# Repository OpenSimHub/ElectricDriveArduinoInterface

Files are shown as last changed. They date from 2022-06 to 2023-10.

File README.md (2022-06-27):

# ElectricDriveArduinoInterface

This repositoy contains the source files for the Electric Drive Ardunio Interface that was developed during the Master's Thesis of [@AnnikenKva](https://github.com/AnnikenKva) at the [University of South-Eastern Norway](https://www.usn.no) in Spring 2022.

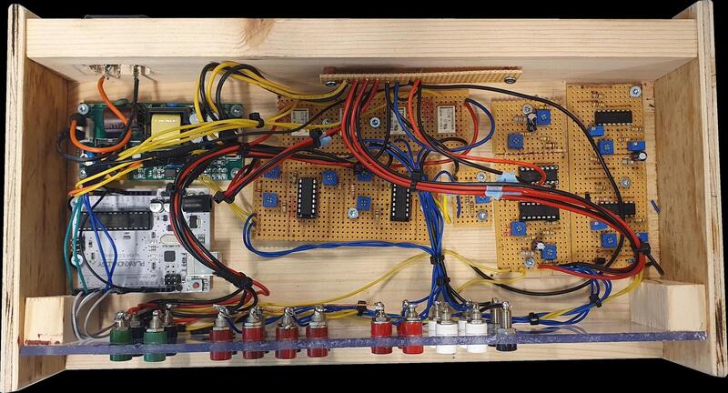
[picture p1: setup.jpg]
Image of physical setup


## Repository description

The repository is organised in the following way:

 * [`arduino/`](arduino): Sourcefile of Arduino programme
 * [`autocad/`](autocad): AutoCAD design file for the different board layouts
 * [`pdf/`](pdf): PDF files of the different board layouts
 * [`python/`](python): Source file for the Python scripts

In addtions the list of components can be found in
 * [`CompList.ods`](CompList.ods)

## License

Copyright &copy; 2022
*  [@AnnikenKva](https://github.com/AnnikenKva) and [@dietmarw](https://github.com/dietmarw)

All files in this repository are subject to the terms of the [Creative Commons Attribution-ShareAlike 4.0 International Public License](LICENSE).

## Contact

In case of questions or suggestions, feel free to open an issue or contact [@AnnikenKva](https://github.com/AnnikenKva) and [@dietmarw](https://github.com/dietmarw) directly.

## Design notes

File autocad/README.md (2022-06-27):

# File Description

 * [`05t010vero.dwg`](05t010vero.dwg): Stripboard layout for 0 − 5 V to 0 − 10 V converter circuit (editable file).
 * [`05tpm10vero.dwg`](05tpm10vero.dwg): Stripboard layout for 0 − 5 V to +- 10 V converter circuit (editable file).
 * [`420t05vero.dwg`](420t05vero.dwg): Stripboard layout for 4 - 20 mA to 0 − 5 V converter circuit (editable file).
 * [`pm10t05vero.dwg`](pm10t05vero.dwg): Stripboard layout for +- 10 V to 0 − 5 V converter circuit (editable file).
 * [`relaysvero.dwg`](relaysvero.dwg): Stripboard layout for 4-channel relay board (editable file).
 * [`fullWir.dwg`](fullWir.dwg): Full internal wiring diagram (editable file).
 * [`cBoxLayout.dwg`](cBoxLayout.dwg): Converter box xomponent layout / placement (editable file).

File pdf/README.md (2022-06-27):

# File Description

 * [`05t010vero.pdf`](05t010vero.pdf): Stripboard layout for 0 − 5 V to 0 − 10 V converter circuit (pdf file).
 * [`05tpm10vero.pdf`](05tpm10vero.pdf): Stripboard layout for 0 − 5 V to +- 10 V converter circuit (pdf file).
 * [`420t05vero.pdf`](420t05vero.pdf): Stripboard layout for 4 - 20 mA to 0 − 5 V converter circuit (pdf file).
 * [`pm10t05vero.pdf`](pm10t05vero.pdf): Stripboard layout for +- 10 V to 0 − 5 V converter circuit (pdf file).
 * [`relaysvero.pdf`](relaysvero.pdf): Stripboard layout for 4-channel relay board (pdf file).
 * [`fullWir.pdf`](fullWir.pdf): Full internal wiring diagram (pdf file).
 * [`cBoxLayout.pdf`](cBoxLayout.pdf): Converter box xomponent layout / placement (pdf file).

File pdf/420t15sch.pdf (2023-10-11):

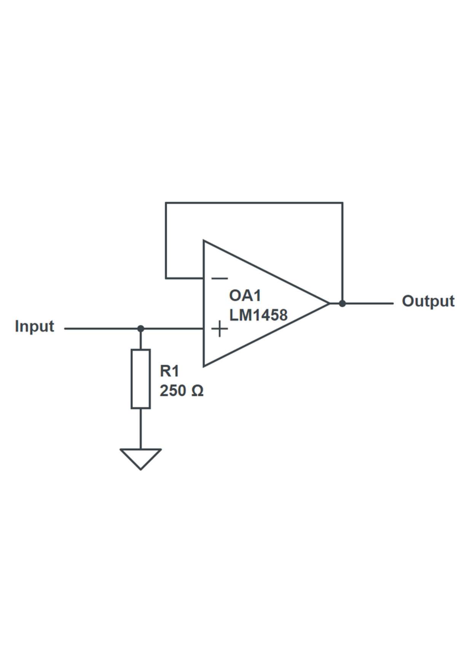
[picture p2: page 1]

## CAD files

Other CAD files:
autocad/fullWir.dwg
autocad/420t15vero.dwg
autocad/pm10t05vero.dwg
autocad/cBoxLayout.dwg
autocad/05t010vero.dwg
autocad/relaysvero.dwg
autocad/05tpm10vero.dwg

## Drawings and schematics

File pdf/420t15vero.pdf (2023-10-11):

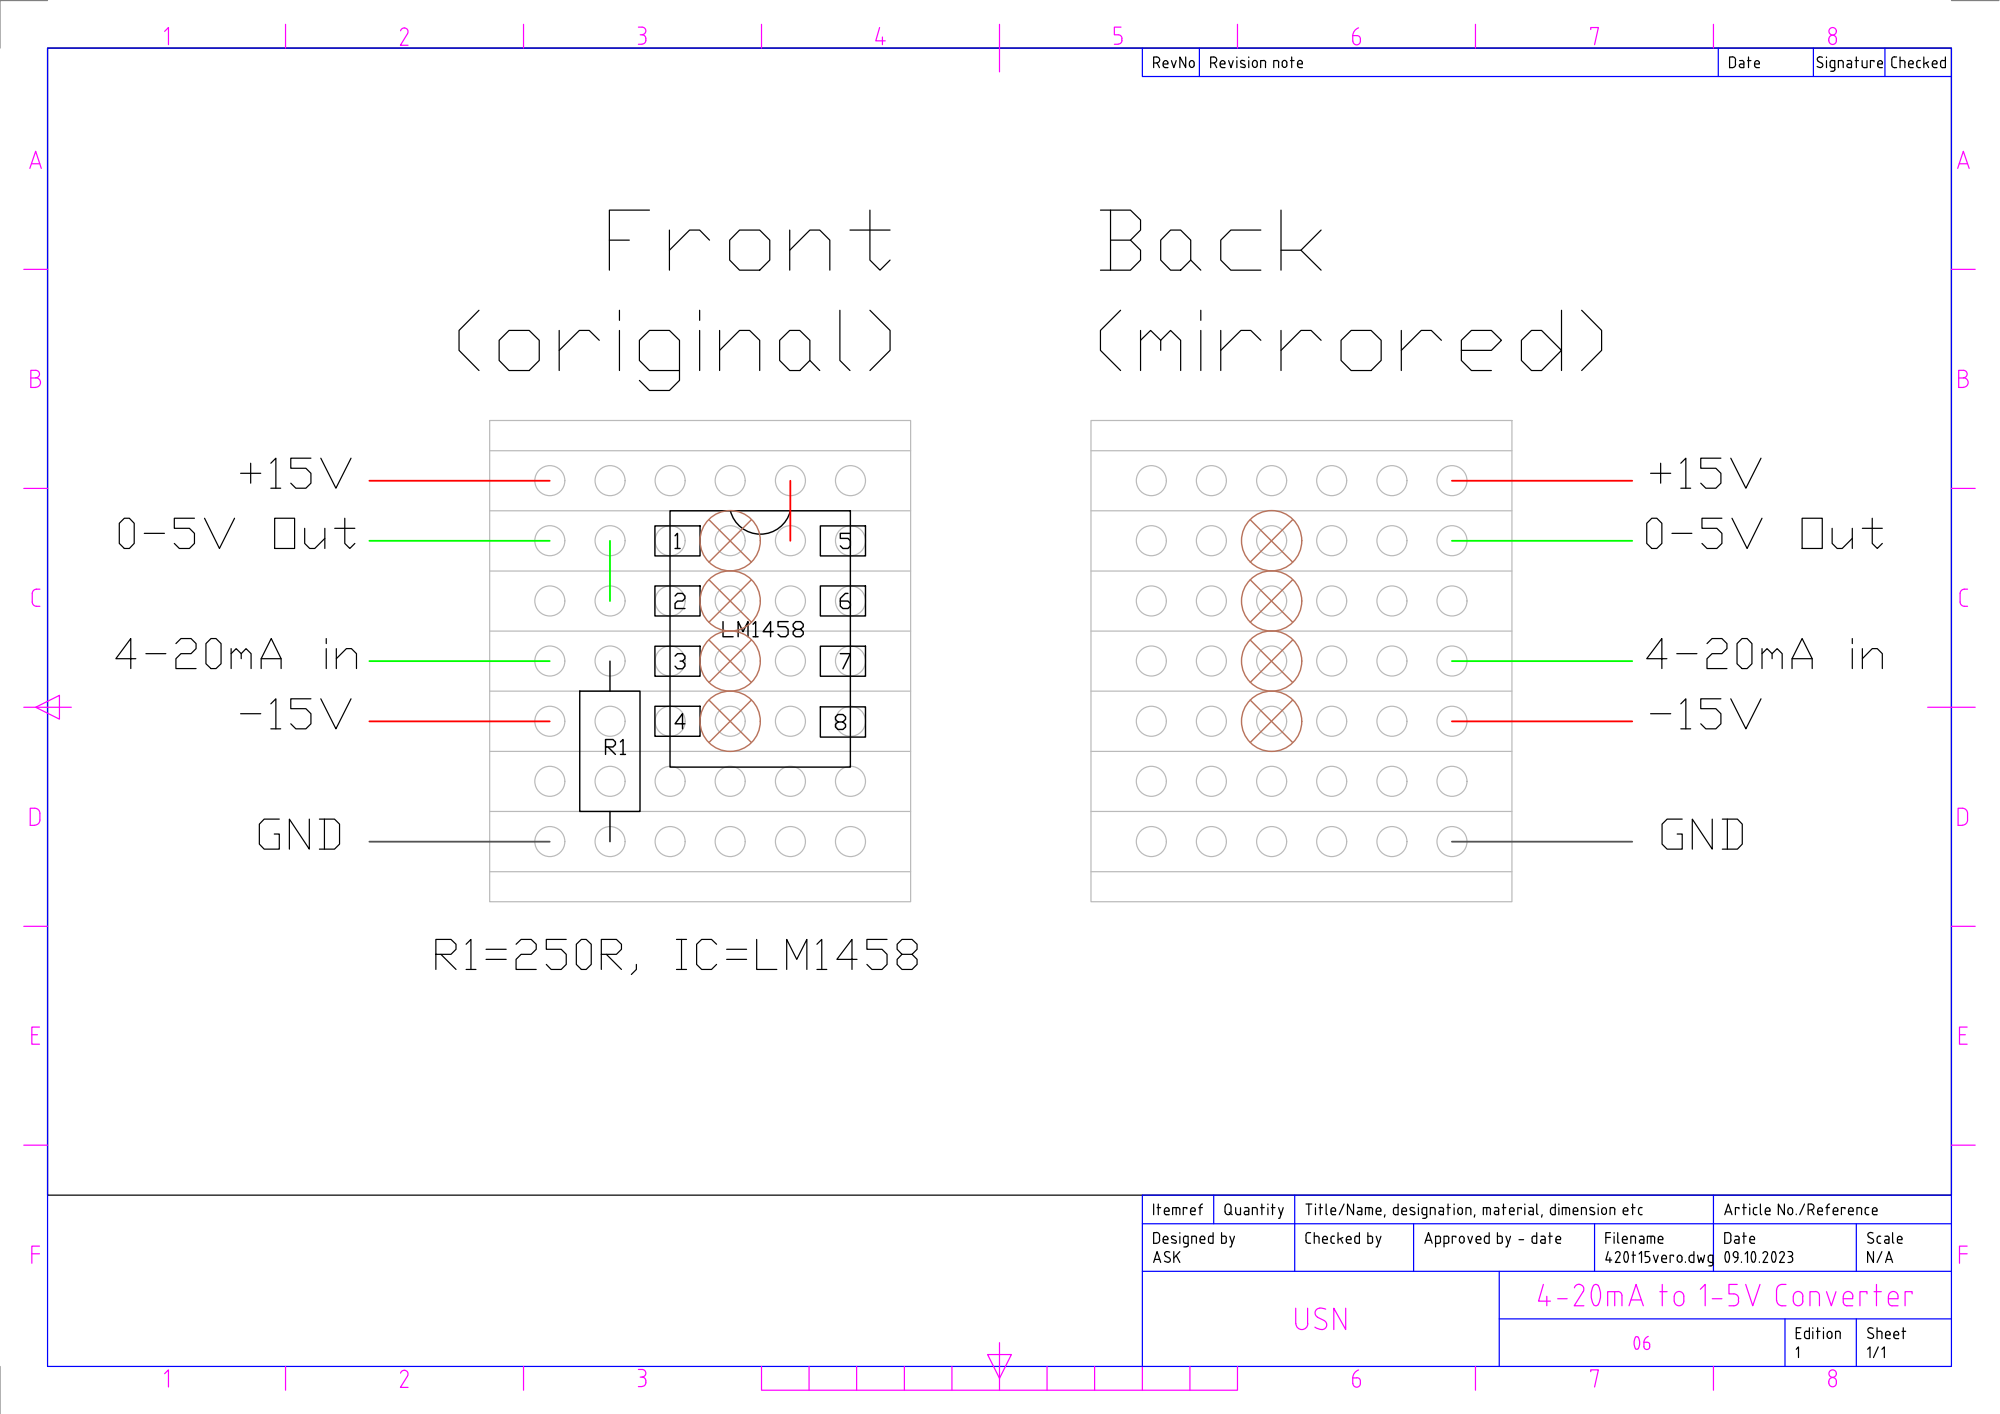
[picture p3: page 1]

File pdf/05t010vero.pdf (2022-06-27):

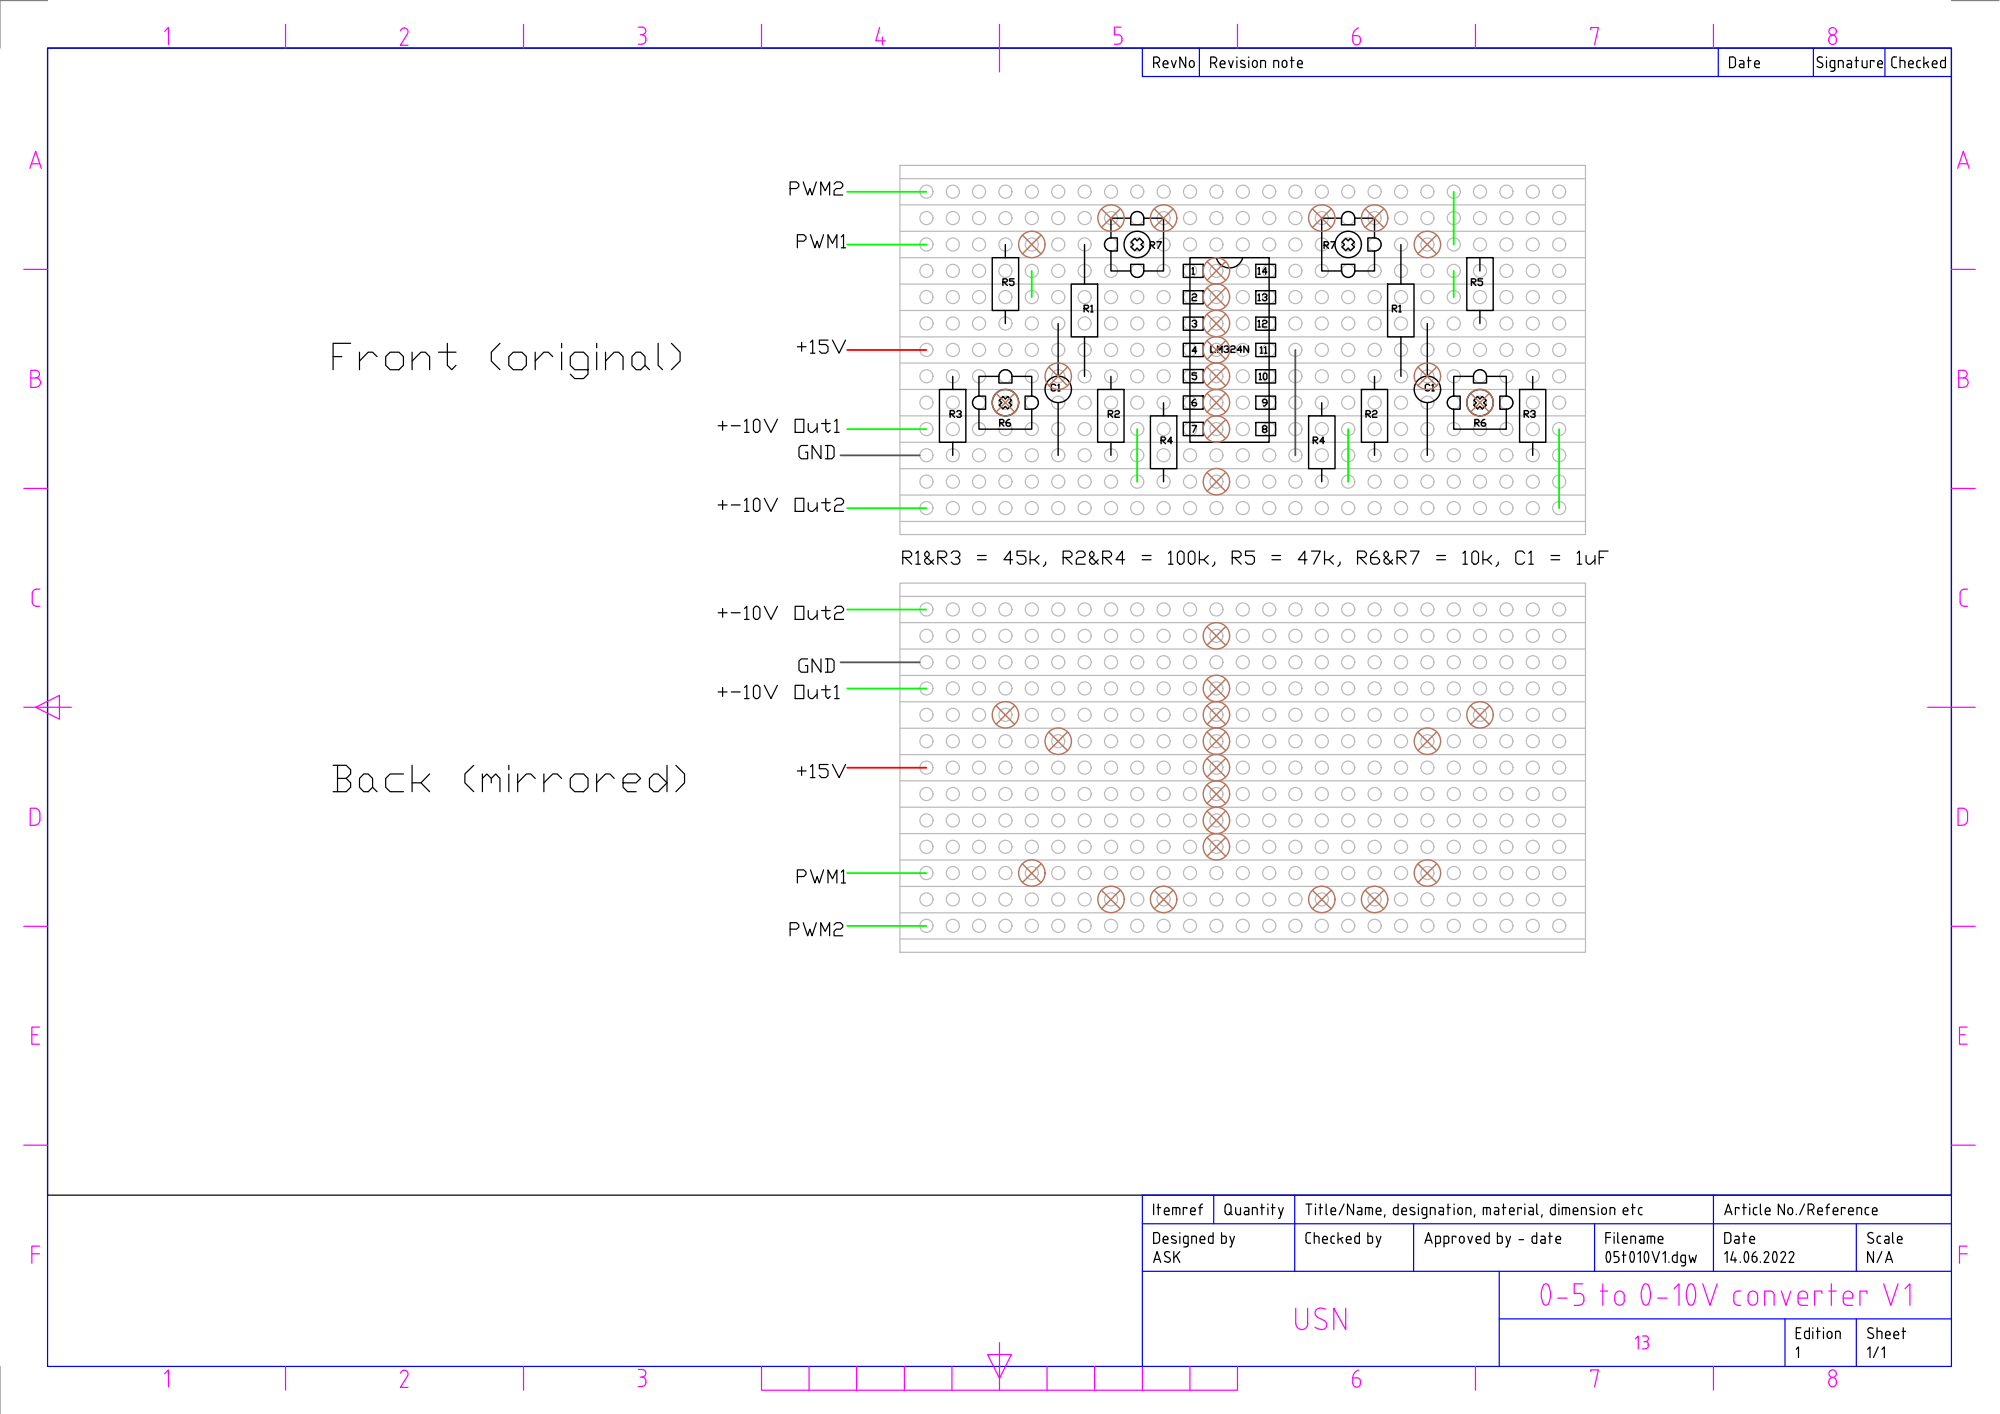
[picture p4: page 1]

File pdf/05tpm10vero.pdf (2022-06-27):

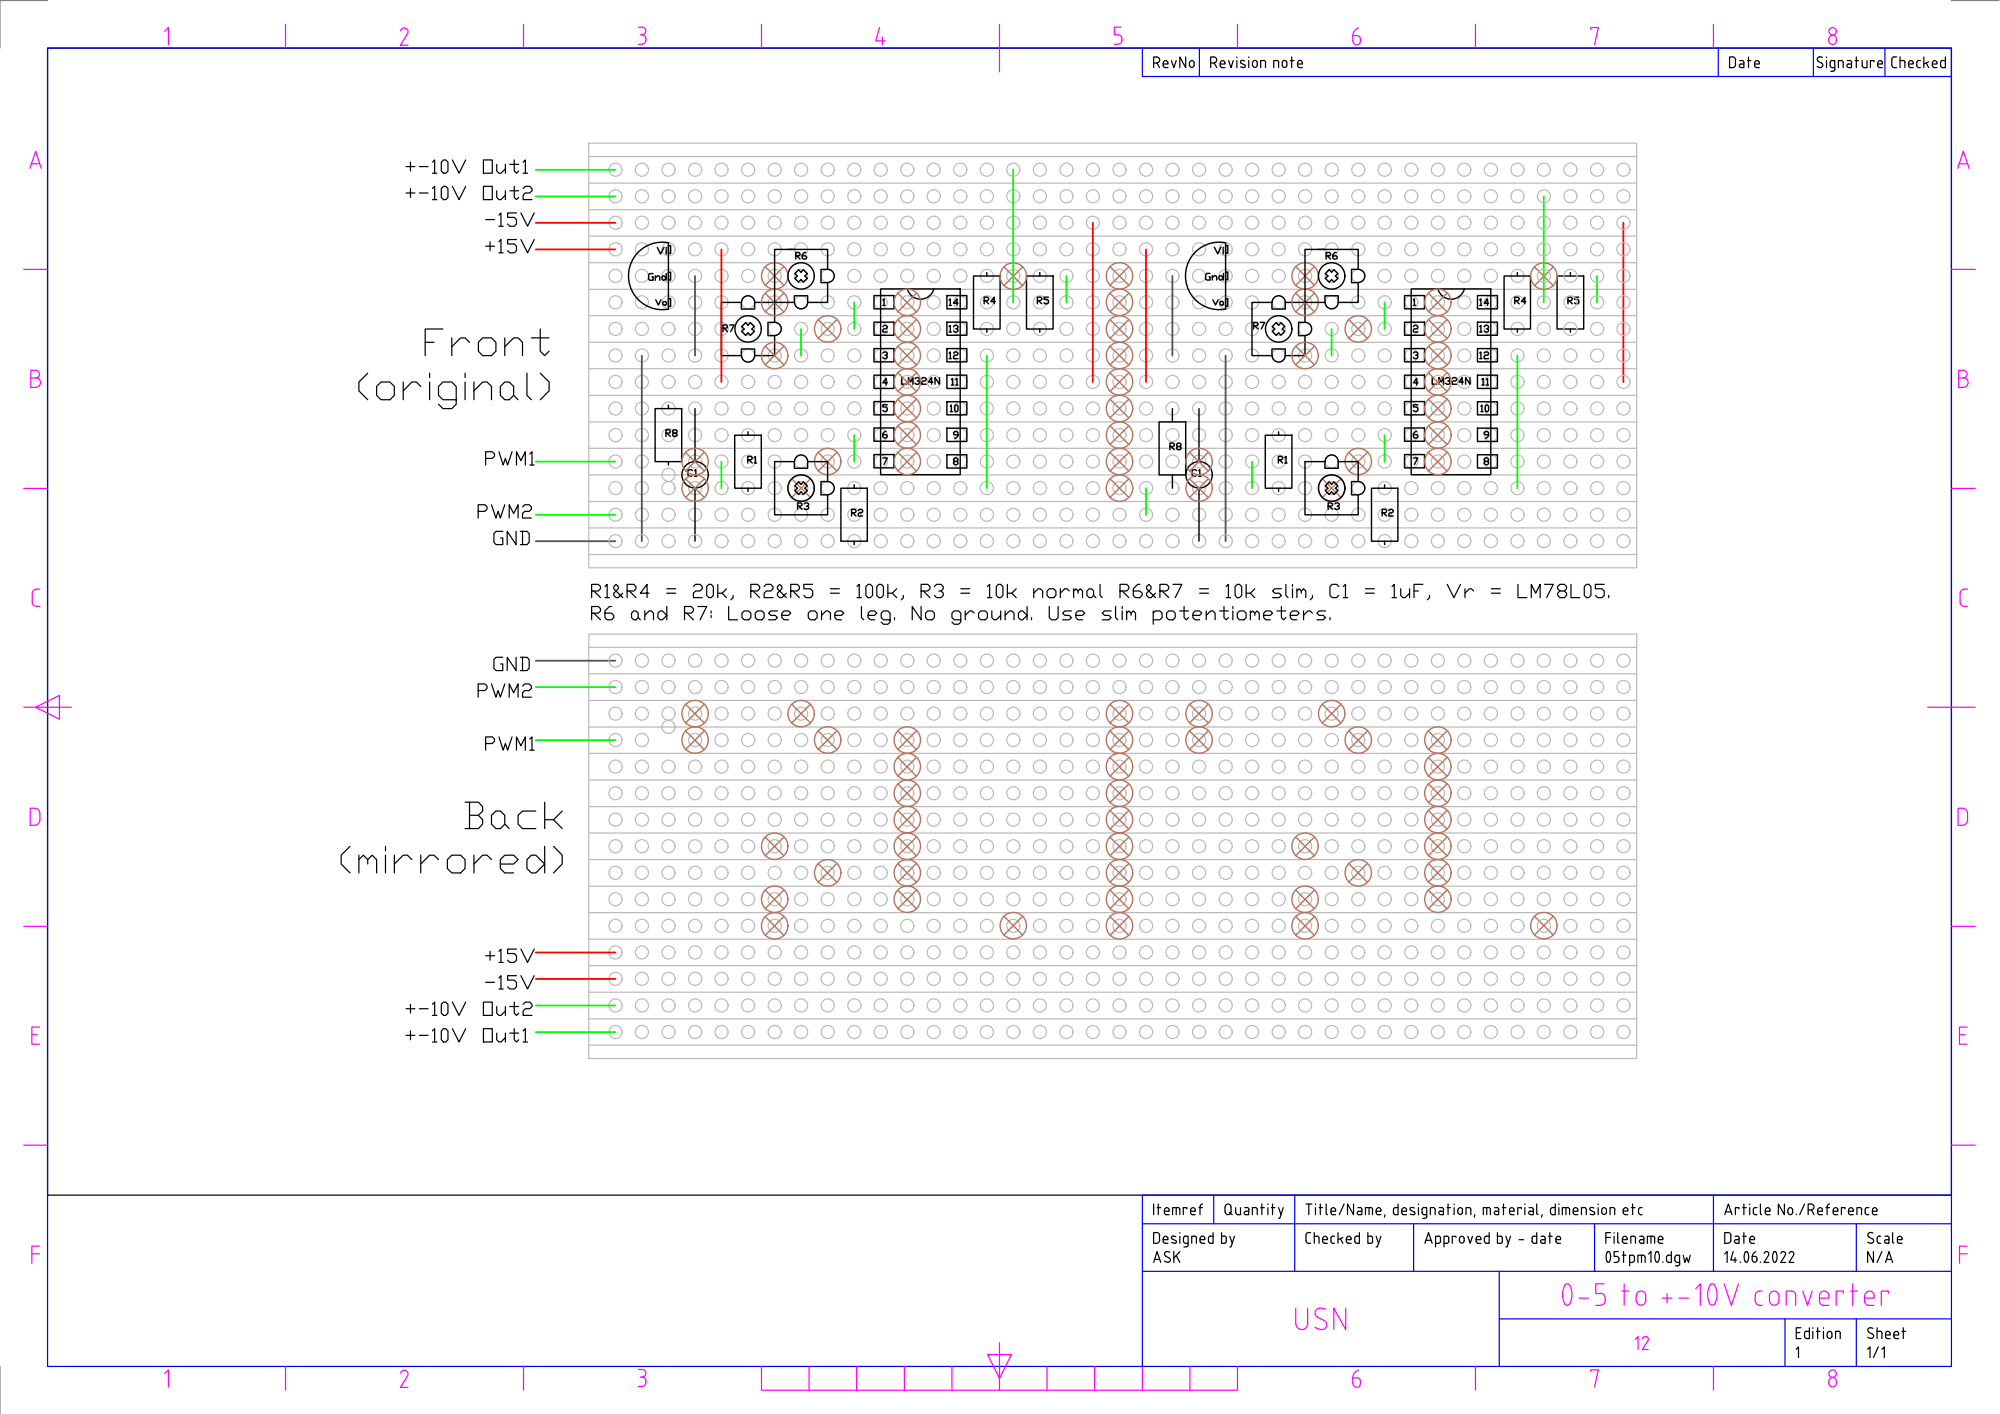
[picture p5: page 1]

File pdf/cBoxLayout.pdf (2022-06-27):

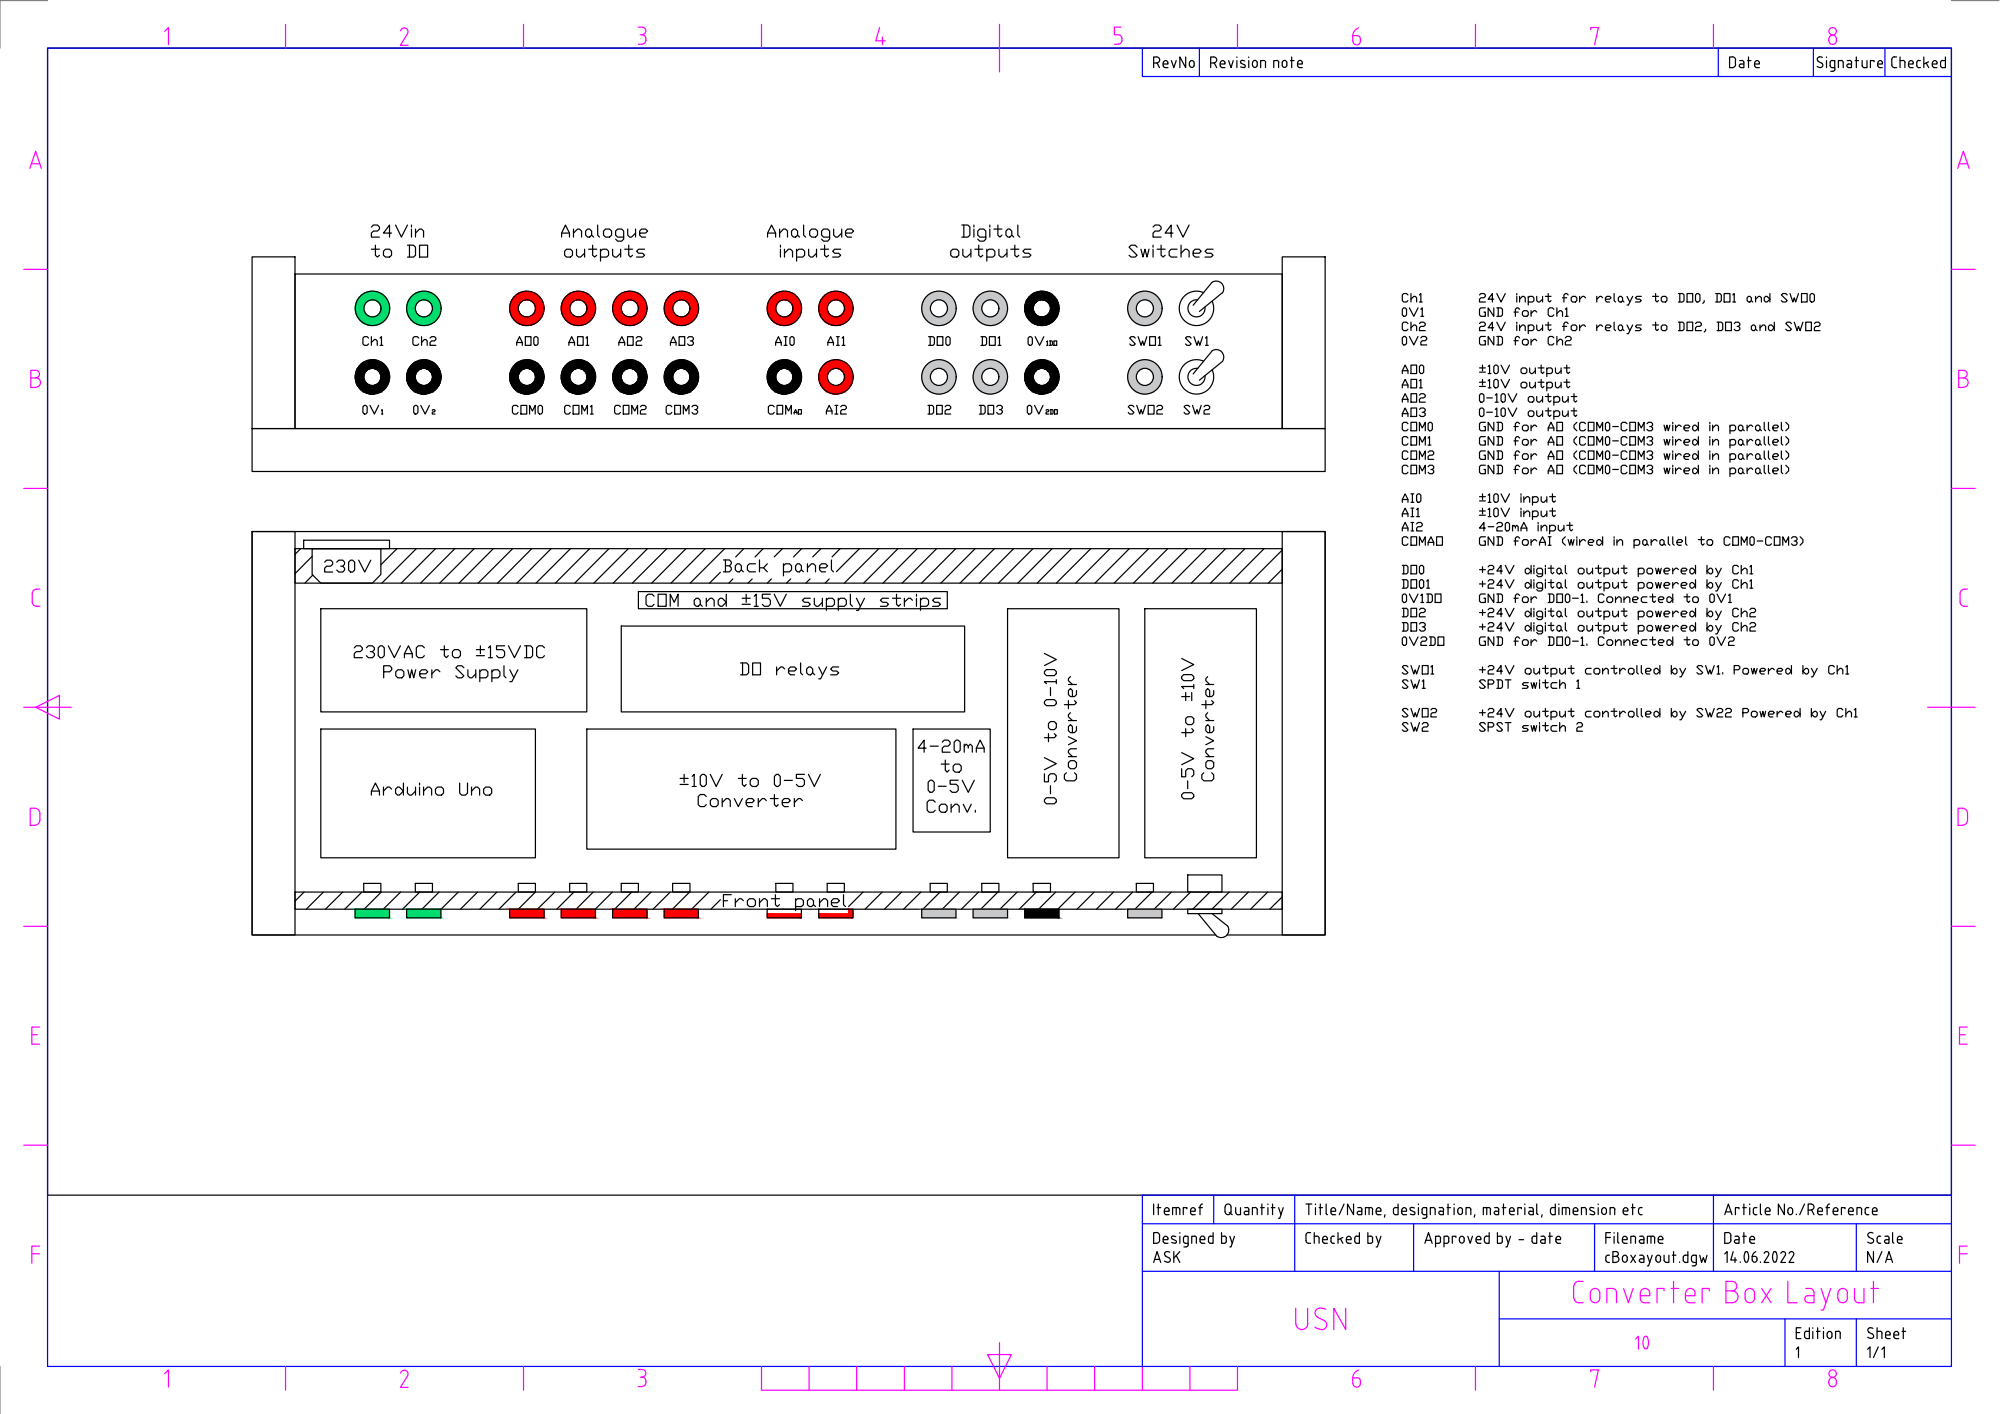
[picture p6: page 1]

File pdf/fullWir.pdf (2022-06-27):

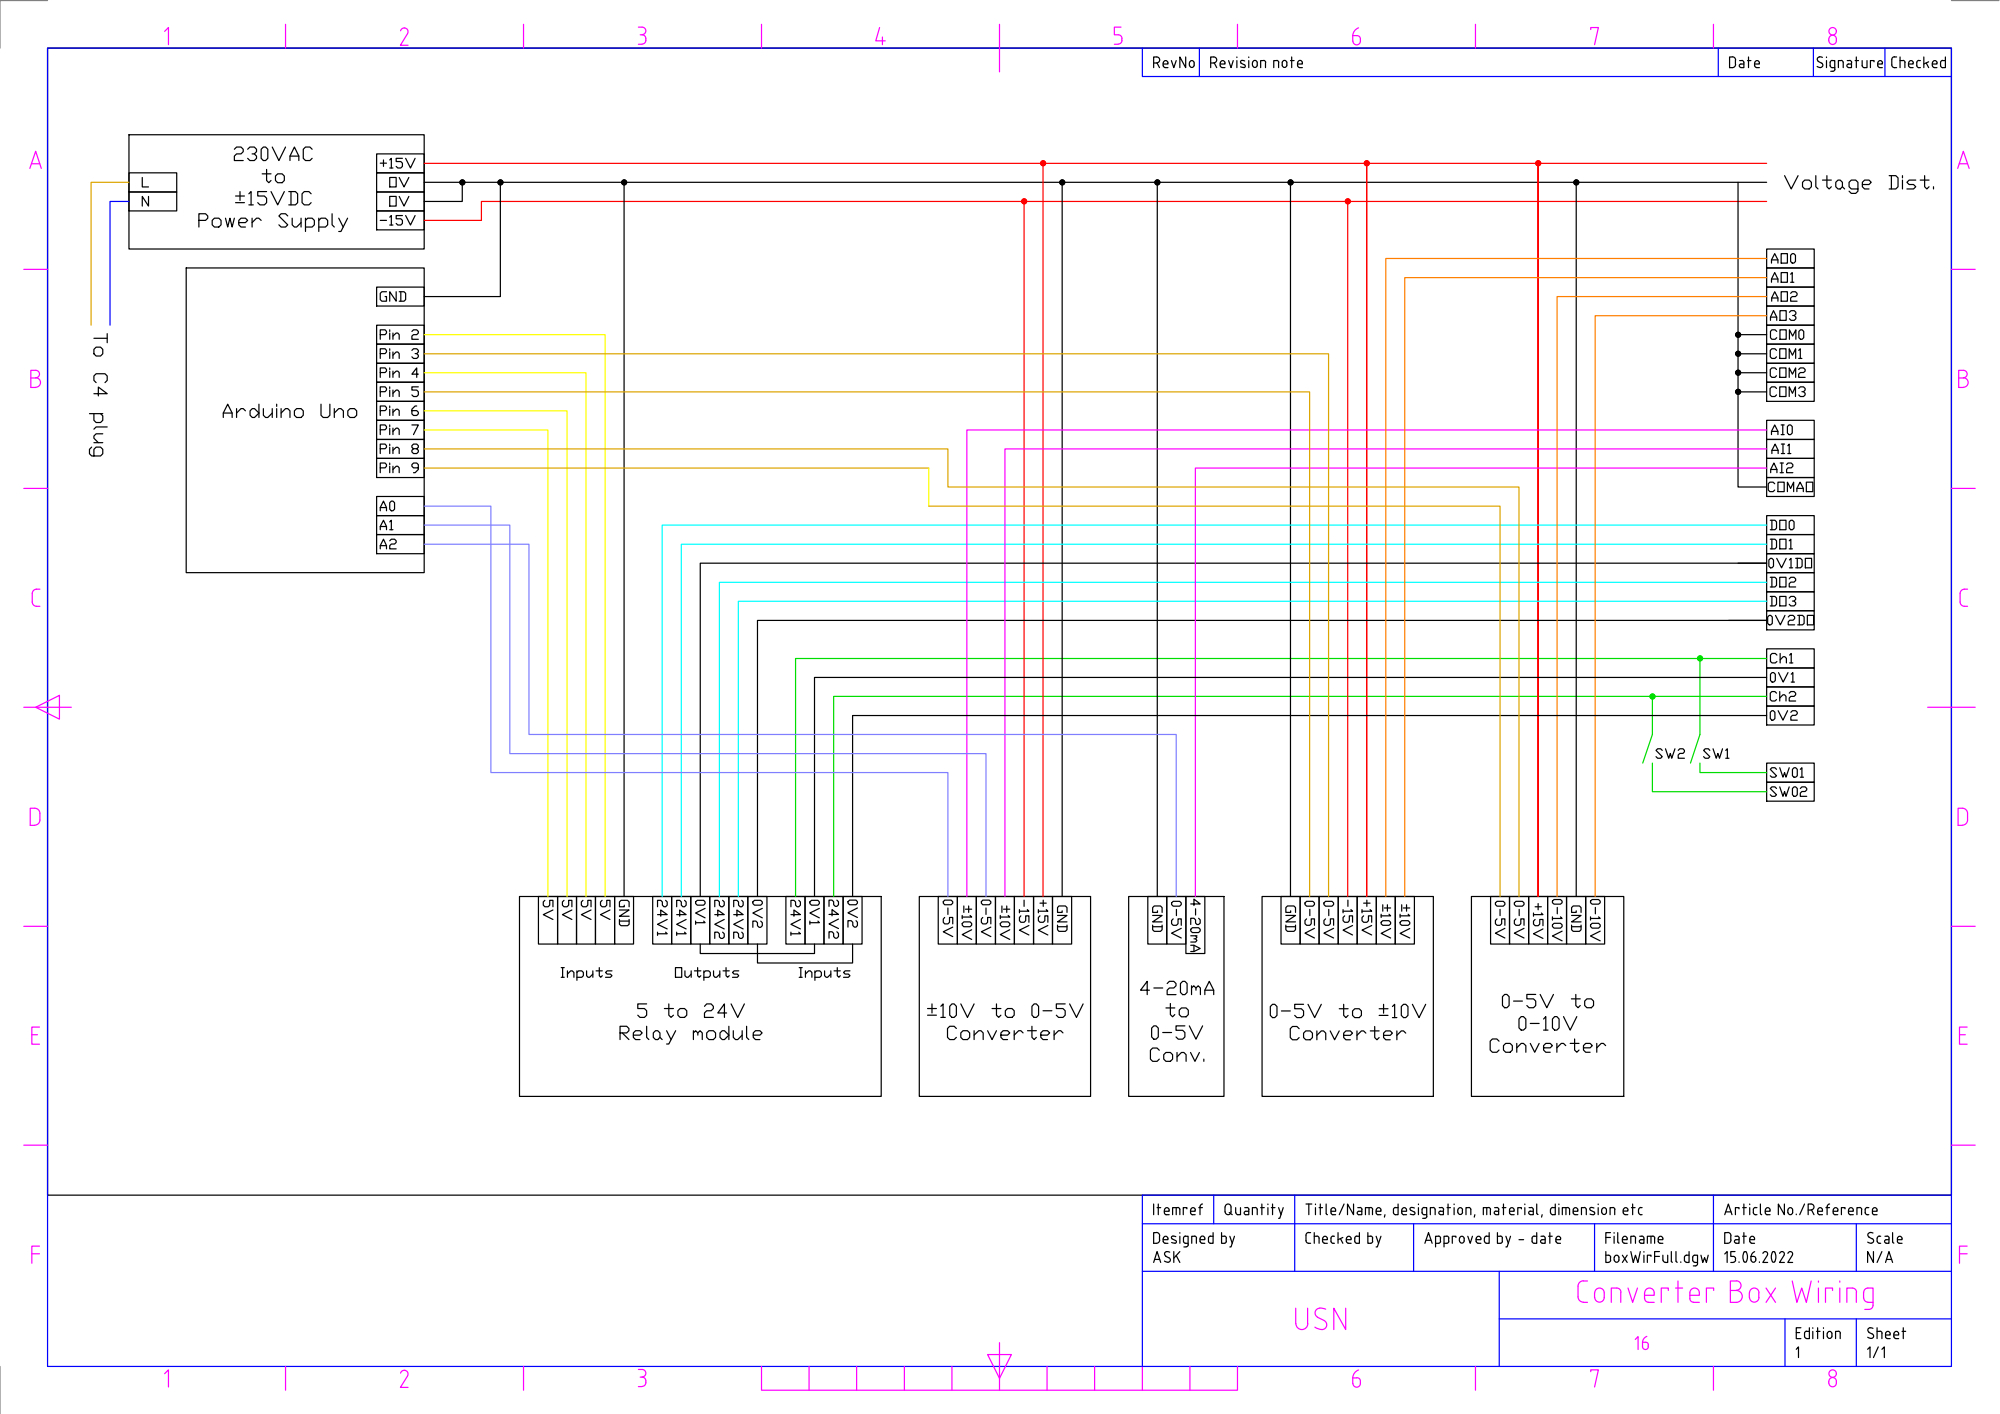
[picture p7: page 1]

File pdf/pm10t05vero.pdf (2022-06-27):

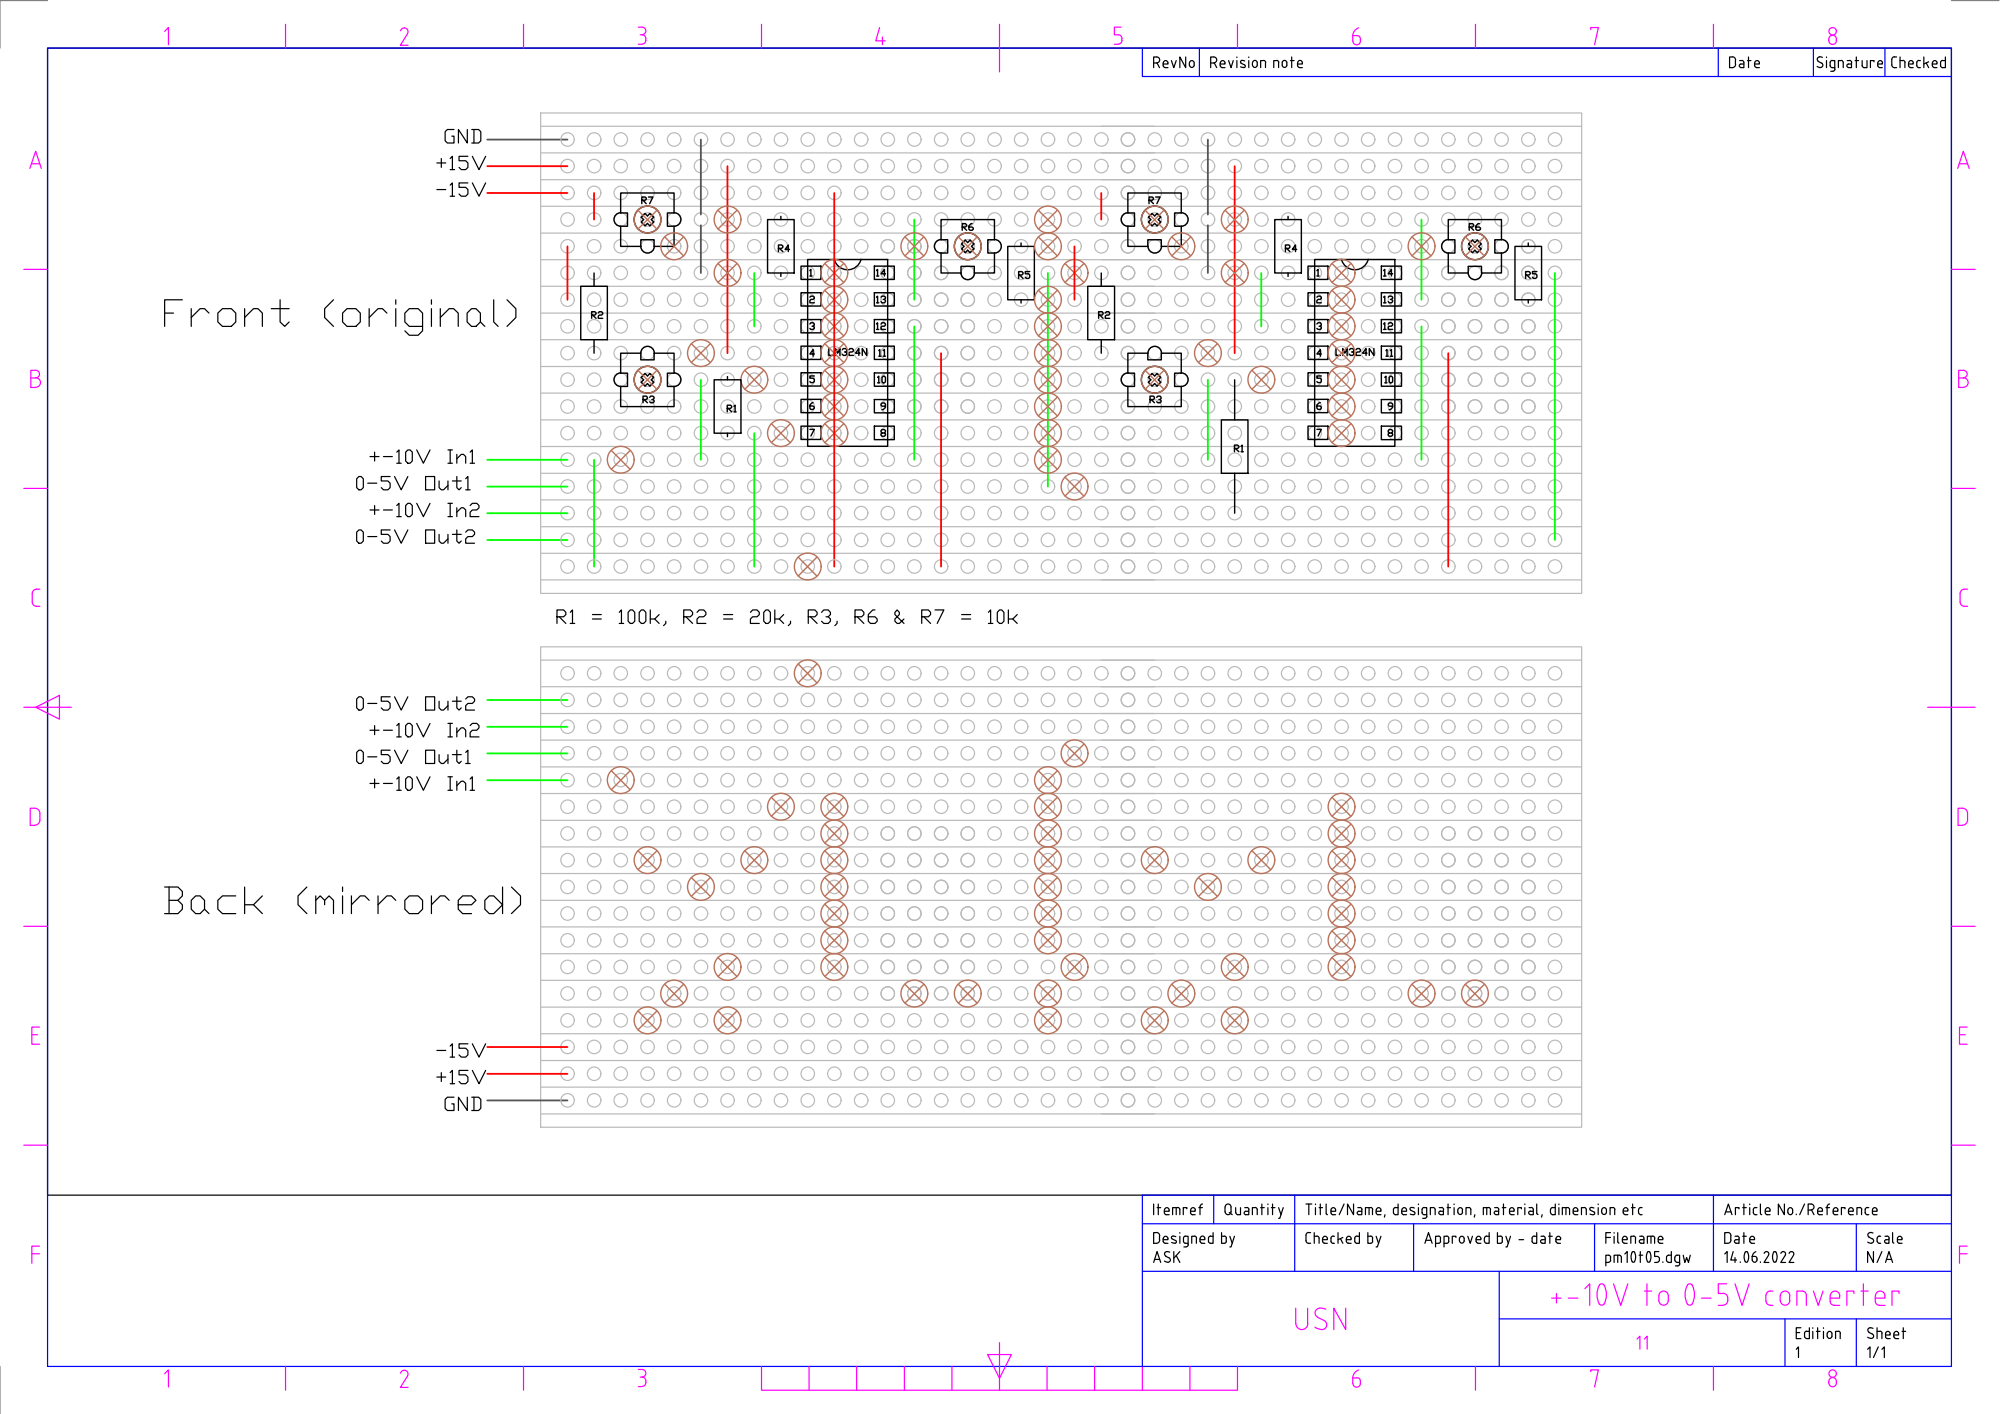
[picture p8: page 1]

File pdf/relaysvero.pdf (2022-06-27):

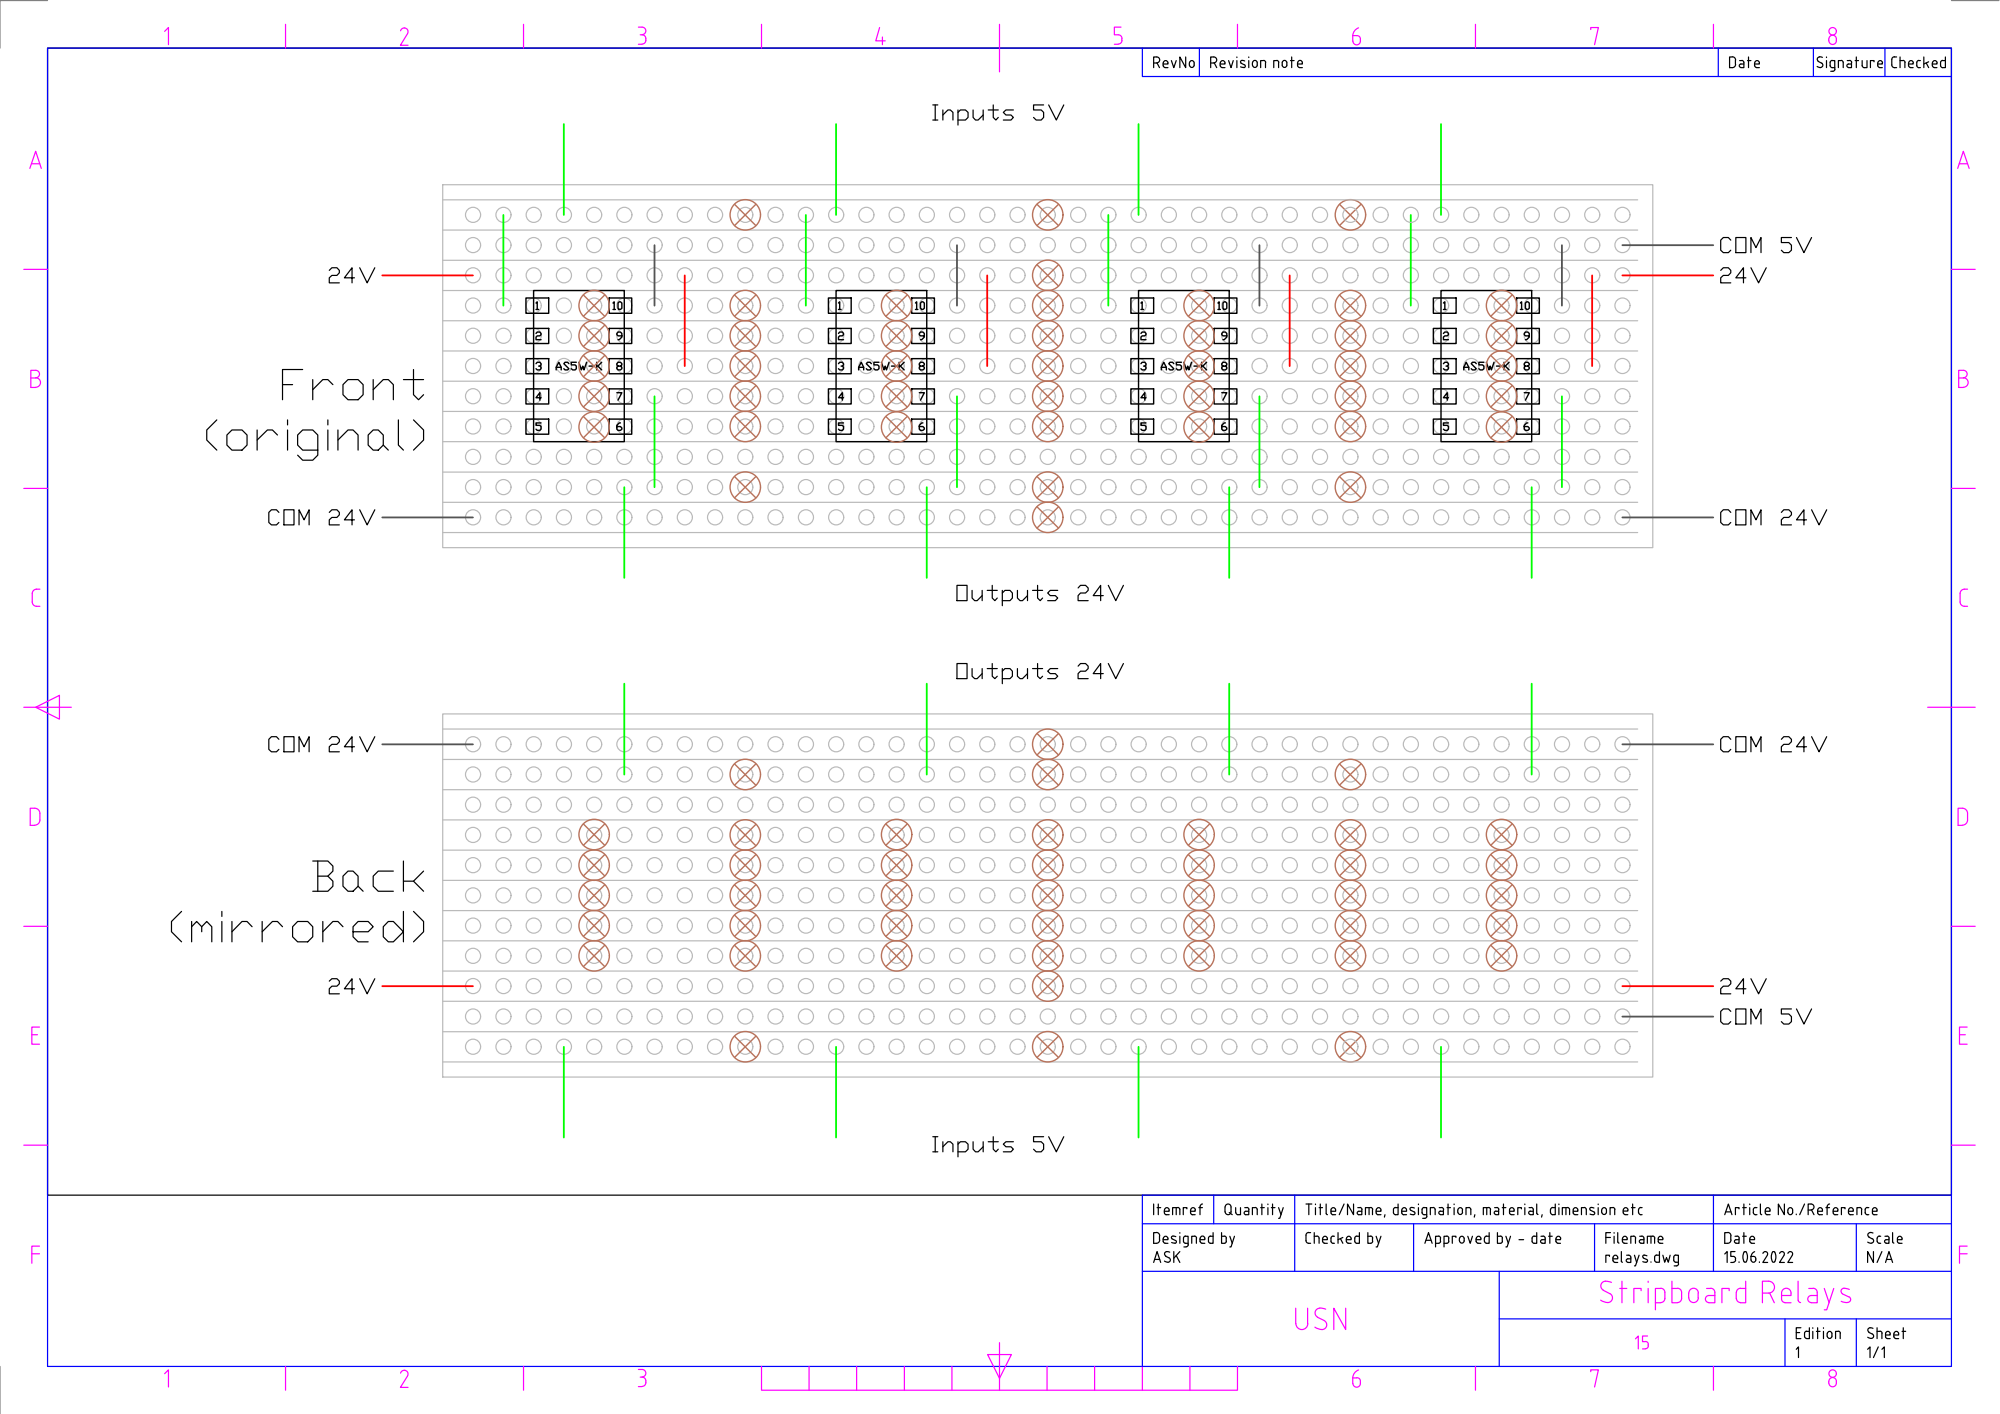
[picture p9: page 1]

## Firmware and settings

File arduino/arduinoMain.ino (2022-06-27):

/* Sketch for ARDUINO communication with Python.
 *  
 *  Part of master's thesis spring 2022.
 *  Anniken Semb Kvalsund
 *  Electrical Power Engineering.
 *  
 */

// Constants
const int AI[3] = {A0, A1, A2}; // Creates an array of all the analog inputs
byte noAI = (sizeof(AI)/sizeof(AI[0]));   // Finds the number of elements in AI array. To use in for loops etc

// Variables
int data1 = 0;          // Input information. Initialise to zero.
int i = 0;

bool readAI = false;
bool writeADO = false;
bool calibrateAO = false;
bool LEDcontr = false;

int AIs[10];            // For "storing" collected analogue input values
char AIstring[16];      // For storing AI values converted to string

// Write data constants and variables
const byte numChars = 16;
char receivedChars[numChars];   // an array to store the received data
byte ndx = 0;
boolean newData = false;
char analogDigital;
int channel;   // Converts the number recieved in channel number to an int
int chValConv; // Sends the char chVal to string toInt function, returned scaled and converted to int.
int outVal; // Output value to analogue PWM outputs.
bool LEDon = false; // LED controlling variable.

// Maxvalue to PWM outputs. Adjustable to ensure 5V, not more, is output at max.
int max_out_AO0 = 255; 
int max_out_AO1 = 255;
int max_out_AO2 = 255;
int max_out_AO3 = 255;

// Declare outputs
const int DO0 = 2;
const int DO1 = 4;
const int DO2 = 7;
const int DO3 = 8;

const int AO0 = 3;      // 0-10V
const int AO1 = 5;      // 0-10V
const int AO2 = 6;      // +-10V
const int AO3 = 9;      // +-10V


void setup() {
  // Setting up an initialise the serial communication
  Serial.begin(9600);       
  pinMode(LED_BUILTIN, OUTPUT);
  pinMode(DO0, OUTPUT);
  pinMode(DO1, OUTPUT);
  pinMode(DO2, OUTPUT);
  pinMode(DO3, OUTPUT);
  pinMode(AO0, OUTPUT);
  pinMode(AO1, OUTPUT);
  pinMode(AO2, OUTPUT);
  pinMode(AO3, OUTPUT);

}



void loop() {
if(Serial.available()>0){           // Return the number of bytes available on serial. if <0, = no info on serial.
  
  recvWithEndMarker();

  if(readAI == true){
    analoginputs();
    readAI = false;
  }

  if(writeADO == true){
    analogueOut();
    writeADO = false;
  }

  if(calibrateAO == true){
    calibrateAO_func();
    calibrateAO = false;
  }

  if (LEDcontr == true){
    LEDonoff();
    LEDcontr = false;
  }
  
  else{/* Do nothing*/}
  } // if serial available
} // Void loop 

//_____________________________________________________________________________________________
// Read analogue inputs

void analoginputs(){ 
  for ( i=0; i<=noAI; i++){
     AIs[i] = analogRead(AI[i]);
   } // for AI

   // Converting the analog input values to a single string with x's separating each value.
   sprintf(AIstring, "%dx%dx%d" , AIs[0],AIs[1],AIs[2]);                  
   Serial.println(AIstring);       // Writes data from AI to serial bus   
} // void analoginputs


//_____________________________________________________________________________________________
// Reads from Serial port until endChar '\n' is received.

void recvWithEndMarker() {
  char endMarker = '\n';
  char rc;
  boolean done = false;

  while (Serial.available() && !done) {
    rc = Serial.read();
    if (rc == endMarker) {
      done = true;
      newData  = true;
    }
    else {
      receivedChars[ndx++] = rc;
      if (ndx >= numChars)
        done = true;
    }
  }

  if (newData) {
    if (!parseInput()) { // if we call parseData it fails there is no need to process that data further.
      //Serial.println("String couldn't be parsed");
      newData = false;
    }
    ndx = 0;
  }
}


//_____________________________________________________________________________________________
// Splits the received string into its separate characters and stores them in globals

boolean parseInput() {
  int secondX = -1;
  String tempString;
  String chValConvtemp;
  char Buf[2];      // For converting string to char
  

  for (int i = 0; i < ndx; i++)
    //Serial.print(receivedChars[i]);
    //Serial.println();

  if (receivedChars[1] != 'x'){   // If no further values are read, ie not split by x'es
     if (receivedChars[0] == 'e'){ readAI = true;} // The readAI value is set to true, causing readAI function to run
     if (receivedChars[0] == 'h'){ LEDcontr = true; LEDon = true;}
     if (receivedChars[0] == 'i'){ LEDcontr = true; LEDon = false;}
    return false;}
  else {                          // If more than one value is transmitted

    if (receivedChars[0] == 'o' or receivedChars[0] == 'p'){ writeADO = true; analogDigital = receivedChars[0];} // Prepare to write values
    if (receivedChars[0] == 'q'){ calibrateAO = true;}   // Prepare to calibrate (using the same message system as writeADO
    
    for (int i = 3; i < ndx && secondX == -1; i++)
      if (receivedChars[i] == 'x')
        secondX = i;

    if (secondX == -1)
      return false;

    tempString = receivedChars;
    channel = tempString.substring(2, secondX).toInt();
    
    chValConvtemp = tempString.substring(secondX + 1, ndx);
    chValConvtemp.toCharArray(Buf, 2);
    chValConv = int(Buf[0]);

// Print for troubleshooting
    Serial.print("analogDigital -> ");
    Serial.println(analogDigital);
    Serial.print("channel -> ");
    Serial.println(channel);
    Serial.print("chValConv -> ");
    Serial.println(chValConv);
  }
  return true;
}

//_____________________________________________________________________________________________
// Write analogue and / or digital values

void analogueOut() { // Writes to analogue outputs

  if (newData == true) {
    // Result in an array with two elements. One A1/D2 etc and one Value/onoff

    if (analogDigital == 'o') {
      //Serial.println("Analogue");

      switch (channel) {
        case 0:
          //Serial.println("AO0");
          outVal = constrain((map(chValConv, 0, 100, 0, max_out_AO0)), 0, max_out_AO0);
          analogWrite(AO0, outVal);
          break;
        case 1:
          //Serial.println("AO1");
          outVal = constrain((map(chValConv, 0, 100, 0, max_out_AO1)), 0, max_out_AO1);
          analogWrite(AO1, outVal);
          break;
        case 2:
          //Serial.println("AO2");
          outVal = constrain((map(chValConv, 0, 100, 0, max_out_AO2)), 0, max_out_AO2);
          analogWrite(AO2, outVal);
          break;
        case 3:
          //Serial.println("AO3");
          outVal = constrain((map(chValConv, 0, 100, 0, max_out_AO3)), 0, max_out_AO3);
          analogWrite(AO3, outVal);
          break;
        default:
          //Serial.println("NaN");
          break;
      } // Switch case channel

    } // if recievedArray[0]=o

    else if (analogDigital == 'p') {
      //Serial.println("Digital");
      bool dContr = false;

      // Creating a "buffer"
      if (chValConv < 50){dContr = LOW;}
      else if (chValConv >= 50){dContr = HIGH;}
      else {dContr = LOW;}
      
      switch (channel) {
        case 0:
          //Serial.println("DO0");
          digitalWrite(DO0, dContr);
          break;
        case 1:
          //Serial.println("DO1");
          digitalWrite(DO1, dContr);
          break;
        case 2:
          //Serial.println("DO2");
          digitalWrite(DO2, dContr);
          break;
        case 3:
          //Serial.println("DO3");
          digitalWrite(DO3, dContr);
          break;
        default:
          //Serial.println("NaN");
          break;
      } // Switch case channel

    } // if recievedArray[0]=p

    else {
      //Serial.println("Channel not valid");
    } // if recievedArray[0]=p

    newData = false;
  } // if newData True
} // void analogueOut


//_____________________________________________________________________________________________

// Function for converting the recieved value 0-100 to calibration values, or reset cal. vlaues.
int calEq(int range, int measVal, int maxOut){
  int maxOut_tmp; // For storing the value temporary
  
  if (measVal == 114){  // If measVal is 114, aka reset, the max \Out is set to default 255
    maxOut_tmp = 255;
    } // if measVal 114('r')
  else { // If measVal is something else, the recieved value(measVal), scales it to measured voltage(10-11V), corrects the offset and scales the new value to out max
    maxOut_tmp = int(round(range/((range+(float(measVal)/100))/maxOut)));
  } // if measVal is not 114('r')
  
  maxOut = maxOut_tmp; 
  
  return maxOut;
  }
  
//_____________________________________________________________________________________________

void calibrateAO_func() { // Calibrate analogue PWM outs

  int range = 0; // Range of values. Set to 10 or 20, depending on output channel
  if (channel == 0 or channel == 1){range = 20;} // For AO_0 and AO_1 with -10 to +10V range
  else {range = 10;} // For AO_2 and AO_3 with 0-10V range.

 // Converted new maximum values for all four channels 
 int new_max_AO0;
 int new_max_AO1;
 int new_max_AO2;
 int new_max_AO3;

  if (newData == true) {
    switch (channel) {
      case 0:
        new_max_AO0 = calEq(range, chValConv, max_out_AO0);
        max_out_AO0 = new_max_AO0; 
        break;
      case 1:
        new_max_AO1 = calEq(range, chValConv, max_out_AO1);
        max_out_AO1 = new_max_AO1; 
        break;
      case 2:
        new_max_AO2 = calEq(range, chValConv, max_out_AO2);
        max_out_AO2 = new_max_AO2; 
        break;
      case 3:
        new_max_AO3 = calEq(range, chValConv, max_out_AO3);
        max_out_AO3 = new_max_AO3; 
        break;
      default:
        //Serial.println("NaN");
        break;
    }  // Switch case channel

    newData = false;
  } // if newData True
}


void LEDonoff(){
  if (LEDon == true) {digitalWrite(LED_BUILTIN, HIGH);}   // switch the LED on}
  //else {digitalWrite(LED_BUILTIN, LOW);}   // turn the LED off}
} // Woid LEDonoff

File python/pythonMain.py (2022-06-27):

#!/usr/bin/env python
# coding: utf-8

# # Python Code for IO controller
# 
# Author: Anniken Semb Kvalsund
# 
# This file contains the python code used for communication with an Arduino microcontroller configured as an IO-module. The python program communicates with the Arduino through serial bus.

# **NOTE:**
# Information sent to the Arduino must be bytewise, not as strings, as the Arduino controller reads strings too slow.
# Capital letters, special symbols and lower case a,b,c and d are reserved for ASCII byte representation of integer values between 0-100. 
# 
# If access to port denied, close Arduino IDE and try again.

# ## Main Code

# Importing libraries etc:

# In[1]:


#%pylab notebook
import serial
import time
import numpy as np


# Establishing communication with the serial port. Remember to change the 'COM3' to whichever port is in use. The time.sleep(2) allows for some startup time for the Arduino.

# In[2]:


ser = serial.Serial('COM3', baudrate = 9600, timeout = 1)   # Timeout unit = seconds
time.sleep(2)


# **Scaling function**
# <br> 
# An allround useful function for scaling variables
# 

# In[3]:


# Function to convert value to different scales
def scaleVal(invalue, in_min, in_max, out_min, out_max):                            
    out = ((invalue - in_min)/(in_max-in_min))*(out_max-out_min)+out_min       
    return out

#print(ScaleVal(0,-10,10,-1000,1000))


# 
# **Defining variables** etc.
# numPoints defines how many data point one wants to collect in one round (based on a for-loop). This will eventually be removed in a final stage of the program. The dataList creates a list for said collected datapoints.

# In[4]:


numPoints = 20                       # Number of data rows to be collected. Remove when program is continuously reading.
dataList = np.array([0]*numPoints)   # Create list for data points.           
#AIs = [None]*numPoints]       # Analogue input matrix
whileLoop = True
Ch = ['0','1','2','3']

rounds = 0 # For counting round of AI read

AI_1_temp = [None]*numPoints
AI_2_temp = [None]*numPoints
AI_3_temp = [None]*numPoints


# **Sanitising input function**
# <br>
# Makes the user type in answers until they type in a valid one. <br>
# Found at: https://stackoverflow.com/questions/23294658/asking-the-user-for-input-until-they-give-a-valid-response

# In[5]:


def clean_input(prompt, type_=None, min_=None, max_=None, range_=None):
    if min_ is not None and max_ is not None and max_ < min_:
        raise ValueError("min_ must be less than or equal to max_.")
    while True:
        ui = input(prompt)
        if type_ is not None:
            try:
                ui = type_(ui)
            except ValueError:
                print("Input type must be {0}.".format(type_.__name__))
                continue
        if max_ is not None and ui > max_:
            print("Input must be less than or equal to {0}.".format(max_))
        elif min_ is not None and ui < min_:
            print("Input must be greater than or equal to {0}.".format(min_))
        elif range_ is not None and ui not in range_:
            if isinstance(range_, range):
                template = "Input must be between {0.start} and {0.stop}."
                print(template.format(range_))
            else:
                template = "Input must be {0}."
                if len(range_) == 1:
                    print(template.format(*range_))
                else:
                    expected = " or ".join((
                        ", ".join(str(x) for x in range_[:-1]),
                        str(range_[-1])
                    ))
                    print(template.format(expected))
        else:
            return ui


# ### Functions

# **Read analogue inputs** 
# <br>
# The 'AI_read' function reads values from the analogue inputs (A0-A3). The data is transmitted with 10bit resolution.

# In[6]:


# Function for reading analogue values
def AI_read():    
    #ser.write(b'e')                                     # b signifies that we're writing a byte to the serial bus
    arduinoData = ser.readline().decode().rstrip()      # Reads the arduino point from the ser port specified above. Readline reads until the end of line character. ascii decode removes the information around data read (byte rn)   
    list_values = arduinoData.split('x')                # Splits the multiple elements by x
#    list_values_int = list(map(int, list_values))      # Converts lists of strings to list of integers
    return list_values


# **Sort Collected Data in Matrix**
# <br>
# The function 'sortData' calls the 'AI_read' function, as described above and sorts the arrays into a matrix-form.. Each column in the matrix represents the values collected from one input.

# In[7]:


#Function to sort data in Matrix
def sortData(AI1, AI2, AI3):
    for i in range(0,numPoints):               # Limits number of data transferred. Can be removed later
        ser.write(bytes('e', 'utf-8'))         # calls for an analogue input reading
        ser.write(bytes('\n', 'utf-8'))
        data = AI_read()                       # Call the Function that reads the Analogue values
        #print(data)                            # Prints the recieved data

        # Sorting data from the three different channels to their own array     
        AI_1_temp[i] = round(scaleVal(int(data[0]),0,1023,-10,10),3)
        AI_2_temp[i] = round(scaleVal(int(data[1]),0,1023,-10,10),3)
        AI_3_temp[i] = round(scaleVal(int(data[2]),205,1023,4,20),3)

    AI1_return = AI1 + AI_1_temp
    AI2_return = AI2 + AI_2_temp
    AI3_return = AI3 + AI_3_temp
    
    #print('\nAI 1 = ', AI1_return,'\nAI 2 = ', AI2_return,'\nAI 3 = ', AI3_return,)
    #print('\nAI 1 = ', AI_1, '\nAI 2 = ', AI_2, '\nAI 3 = ', AI_3)
    
    return AI1_return,AI2_return,AI3_return


# **Controlling built in Arduino LED**
# <br>
# The function can switch on and off the built in Arduino LED. It is not a vital function, but comes in handy during troubleshooting plausible connectin issues.

# In[8]:


# Function for controlling built in Arduino LED
def LEDonoff(LEDcontr):
    if LEDcontr == 'on':
        ser.write(bytes('h', 'utf-8'))
        ser.write(bytes('\n', 'utf-8'))
    elif LEDcontr == 'off':
        ser.write(bytes('i', 'utf-8'))
        ser.write(bytes('\n', 'utf-8'))
    arduinoData = ser.readline().decode()
    return arduinoData


# **Limit Function (utils)**
# <br>
# This function makes sure the number is within a specified range. Default is 0-100

# In[9]:


#Limits input 'num' between minimum and maximum values
def limit(num, minimum=0, maximum=100):
    limited = max(min(num, maximum), minimum)
    return limited
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

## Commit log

2022-06-27 Added project files for HardwareX special issue
    Files for "Special Issue on Open Source Machinery and Laboratory Instrument using the Arduino Software and Hardware Ecosystem" of HardwarX
    [05t010vero.dwg, 05tpm10vero.dwg, 420t15vero.dwg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]
2023-10-11 New version of current to voltage converter for revision 2
    [420t15vero.dwg]
